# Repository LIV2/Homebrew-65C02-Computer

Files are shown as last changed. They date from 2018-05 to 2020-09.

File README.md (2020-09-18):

# Homebrew-65C02-Computer

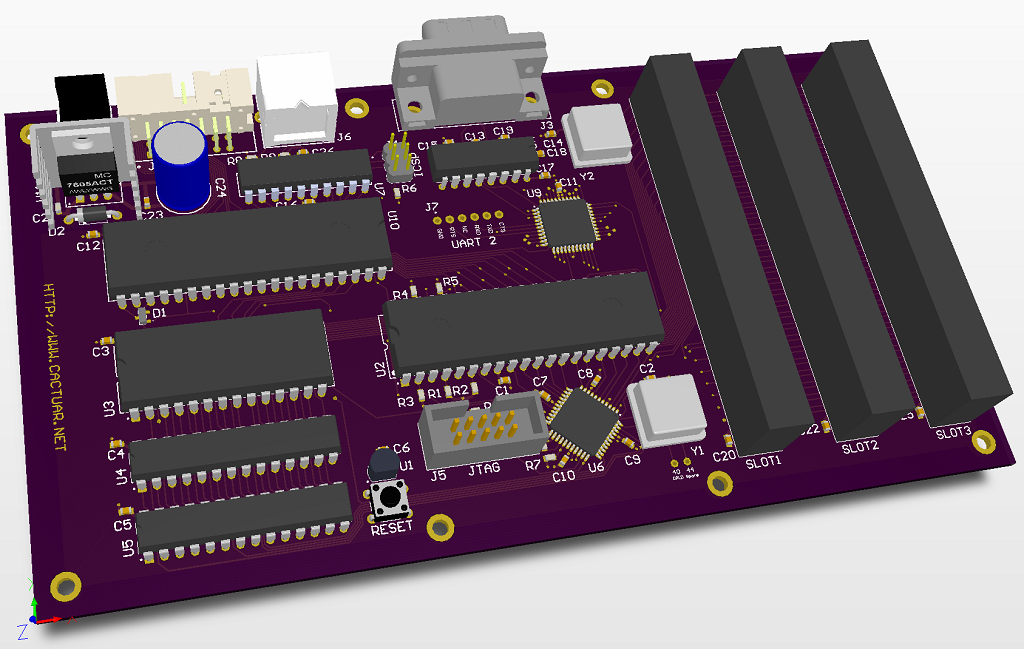
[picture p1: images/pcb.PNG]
PCB


# Introduction
This is a 65C02 based computer with on-board Serial, Parallel IO, PS/2 Keyboard support and 3 expansion slots.  
A VGA card will come later as an expansion card  

I am designing this in Circuitmaker, You can find the Circuitmaker project [here](https://circuitmaker.com/Projects/Details/Matt-Harlum/65C02-Computer-v12)  

# Memory Map
The Memory map I am using is currently as follows:  
0x0000-0xCFFF: RAM  
0xD000-0xD0FF: UART  
0xD100-0xD1FF: VIA  
0xD200-0xD2FF: IO Select 2  
0xD300-0xD3FF: IO Select 3  
0xD400-0xDFFF: Unused  
0xE000-0xFFFF: ROM  
This can be changed to suit your needs simply by changing the configuration of the CPLD.  

# Software
* [PS/2 Keyboard controller](https://github.com/LIV2/AVR-PS2-KBC)
* [ROM](https://github.com/LIV2/MHMON)

# Expansions
* [VGA card](https://github.com/LIV2/VGA-6502)
* [Floppy Disk card](https://github.com/LIV2/65C02-FDC)

----
Creative Commons Attribution 4.0 International License CC BY
Licensed under a [Creative Commons Attribution 4.0 International License (CC BY)](https://creativecommons.org/licenses/by/4.0/).

Except where otherwise noted, this content is published under a [CC BY license](https://creativecommons.org/licenses/by/4.0/), which means that you can copy, redistribute, remix, transform and build upon the content for any purpose even commercially as long as you give appropriate credit, provide a link to the license, and indicate if changes were made. License details: [https://creativecommons.org/licenses/by/4.0/](https://creativecommons.org/licenses/by/4.0/)

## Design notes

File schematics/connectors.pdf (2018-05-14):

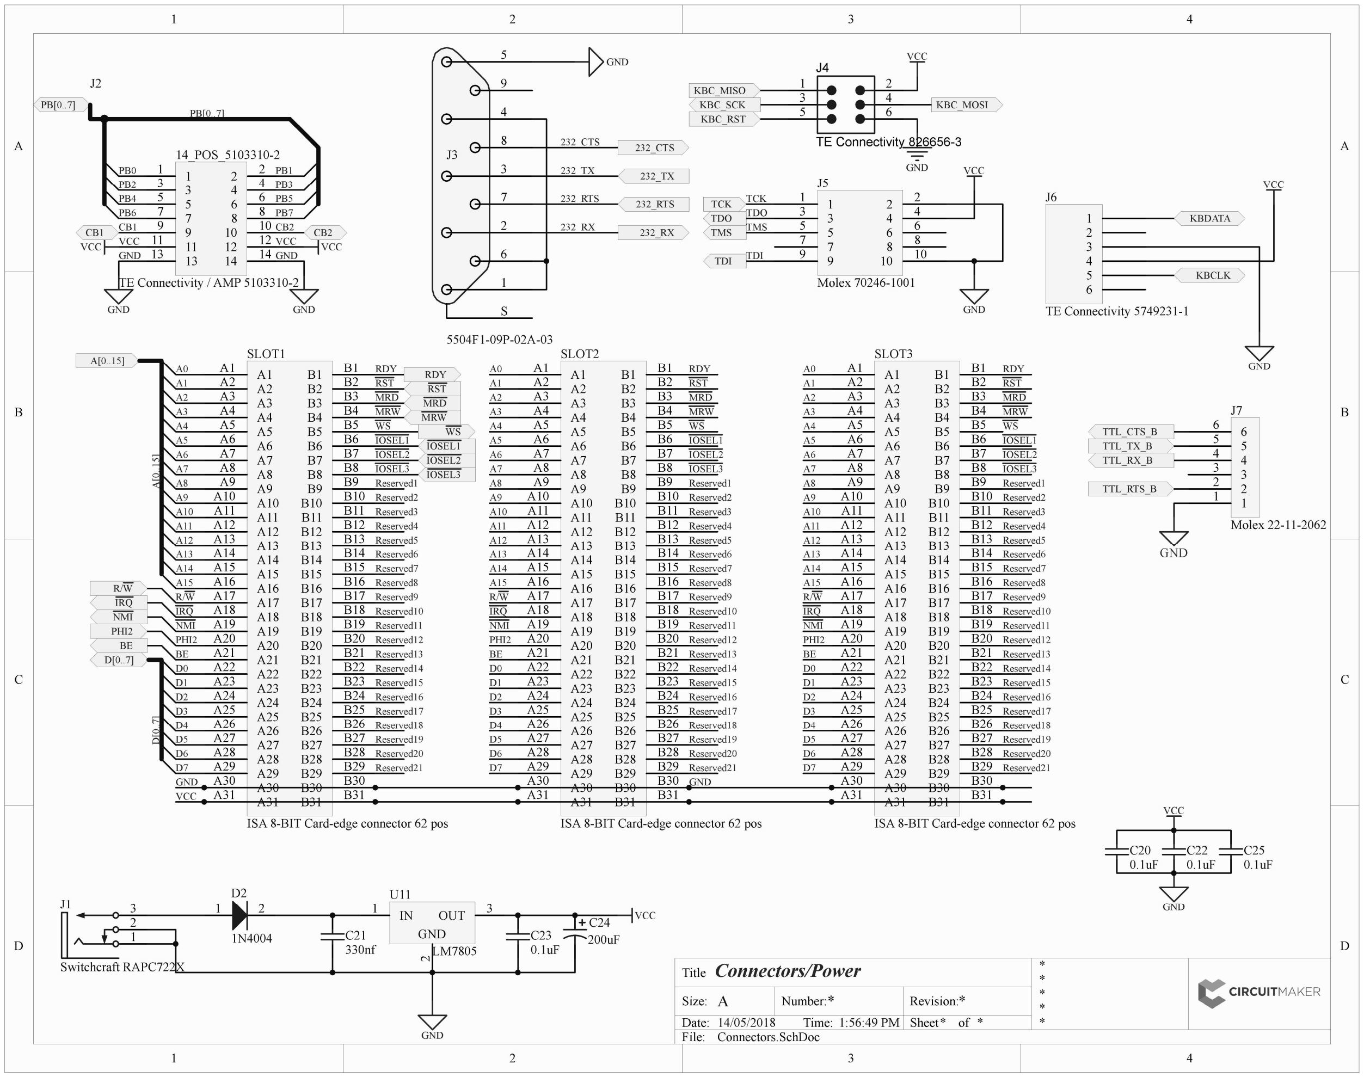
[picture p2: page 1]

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
* | *

## Connectors/Power

* | *
14/05/2018 | 1:56:49 PM
Connectors.SchDoc

Title

Size: | Number:
Date:
File:

Revision:
Time: | Sheet | of

A

PB[0..7]

PB0 | PB1
PB2 | PB3
PB4 | PB5
PB6 | PB7
CB1 | CB2
VCC | VCC
GND | GND
VCC | VCC
GND | GND

232_TX

232_CTS

232_RTS

232_RX

232_CTS

232_TX

232_RTS

232_RX

KBC_MISO

KBC_RST

KBC_SCK | KBC_MOSI

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
TE Connectivity 826656-3

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
10 10

J5

Molex 70246-1001

A1 A1
A2 A2
A3 A3
A4 A4
A5 A5
A6 A6
A7 A7
A8 A8
A9 A9
A10 A10
A11 A11
A12 A12
A13 A13
A14 A14
A15 A15
A16 A16
A17 A17
A18 A18
A19 A19
A20 A20
A21 A21
A22 A22
A23 A23
A24 A24
A25 A25
A26 A26
A27 A27
A28 A28
A29 A29
A30 A30
A31 A31
B1 | B1
B2 | B2
B3 | B3
B4 | B4
B5 | B5
B6 | B6
B7 | B7
B8 | B8
B9 | B9
B10 | B10
B11 | B11
B12 | B12
B13 | B13
B14 | B14
B15 | B15
B16 | B16
B17 | B17
B18 | B18
B19 | B19
B20 | B20
B21 | B21
B22 | B22
B23 | B23
B24 | B24
B25 | B25
B26 | B26
B27 | B27
B28 | B28
B29 | B29
B30 | B30
B31 | B31

SLOT1

ISA 8-BIT Card-edge connector 62 pos

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
PHI2
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
A[0..15]

D[0..7]

R/W
IRQ
NMI

# PHI2 D[0..7] A[0..15]

RDY
RST MRD MRD

MRW MRW
WS WS

3

1

2

J1

Switchcraft RAPC722X

C23
0.1uF

VCC

GND

C21
330nf

C20
0.1uF

A1 A1
A2 A2
A3 A3
A4 A4
A5 A5
A6 A6
A7 A7
A8 A8
A9 A9
A10 A10
A11 A11
A12 A12
A13 A13
A14 A14
A15 A15
A16 A16
A17 A17
A18 A18
A19 A19
A20 A20
A21 A21
A22 A22
A23 A23
A24 A24
A25 A25
A26 A26
A27 A27
A28 A28
A29 A29
A30 A30
A31 A31
B1 | B1
B2 | B2
B3 | B3
B4 | B4
B5 | B5
B6 | B6
B7 | B7
B8 | B8
B9 | B9
B10 | B10
B11 | B11
B12 | B12
B13 | B13
B14 | B14
B15 | B15
B16 | B16
B17 | B17
B18 | B18
B19 | B19
B20 | B20
B21 | B21
B22 | B22
B23 | B23
B24 | B24
B25 | B25
B26 | B26
B27 | B27
B28 | B28
B29 | B29
B30 | B30
B31 | B31

SLOT2

ISA 8-BIT Card-edge connector 62 pos

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
PHI2
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
0.1uF

A1 A1
A2 A2
A3 A3
A4 A4
A5 A5
A6 A6
A7 A7
A8 A8
A9 A9
A10 A10
A11 A11
A12 A12
A13 A13
A14 A14
A15 A15
A16 A16
A17 A17
A18 A18
A19 A19
A20 A20
A21 A21
A22 A22
A23 A23
A24 A24
A25 A25
A26 A26
A27 A27
A28 A28
A29 A29
A30 A30
A31 A31
B1 | B1
B2 | B2
B3 | B3
B4 | B4
B5 | B5
B6 | B6
B7 | B7
B8 | B8
B9 | B9
B10 | B10
B11 | B11
B12 | B12
B13 | B13
B14 | B14
B15 | B15
B16 | B16
B17 | B17
B18 | B18
B19 | B19
B20 | B20
B21 | B21
B22 | B22
B23 | B23
B24 | B24
B25 | B25
B26 | B26
B27 | B27
B28 | B28
B29 | B29
B30 | B30
B31 | B31

SLOT3

ISA 8-BIT Card-edge connector 62 pos

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
PHI2
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
0.1uF

PB[0..7]

BE

CB1 | CB2
WS | WS

KBDATA

KBCLK

VCC

GND

1 2

D2

1N4004

IOSEL1 | IOSEL1
| IOSEL2 IOSEL3

IOSEL2
IOSEL3
Reserved1
Reserved2
Reserved3
Reserved4
Reserved5
Reserved6
Reserved7
Reserved8
Reserved9
Reserved10
Reserved11
Reserved12
Reserved13
Reserved14
Reserved15
Reserved16
Reserved17
Reserved18
Reserved19
Reserved20
Reserved21

IOSEL1
IOSEL2
IOSEL3
Reserved1
Reserved2
Reserved3
Reserved4
Reserved5
Reserved6
Reserved7
Reserved8
Reserved9
Reserved10
Reserved11
Reserved12
Reserved13
Reserved14
Reserved15
Reserved16
Reserved17
Reserved18
Reserved19
Reserved20
Reserved21

IOSEL1
IOSEL2
IOSEL3
Reserved1
Reserved2
Reserved3
Reserved4
Reserved5
Reserved6
Reserved7
Reserved8
Reserved9
Reserved10
Reserved11
Reserved12
Reserved13
Reserved14
Reserved15
Reserved16
Reserved17
Reserved18
Reserved19
Reserved20
Reserved21

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
5504F1-09P-02A-03

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
10 10
11 11 | 12 | 12
13 13 | 14 | 14

14_POS_5103310-2

J2

TE Connectivity / AMP 5103310-2

C24
200uF
IN 1 | OUT | 3 2

GND

U11

LM7805

1
2
3
4
5
6

J6

TE Connectivity 5749231-1

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
Molex 22-11-2062

GND

TTL_RTS_B

TTL_RX_B

TTL_TX_B

TTL_CTS_B

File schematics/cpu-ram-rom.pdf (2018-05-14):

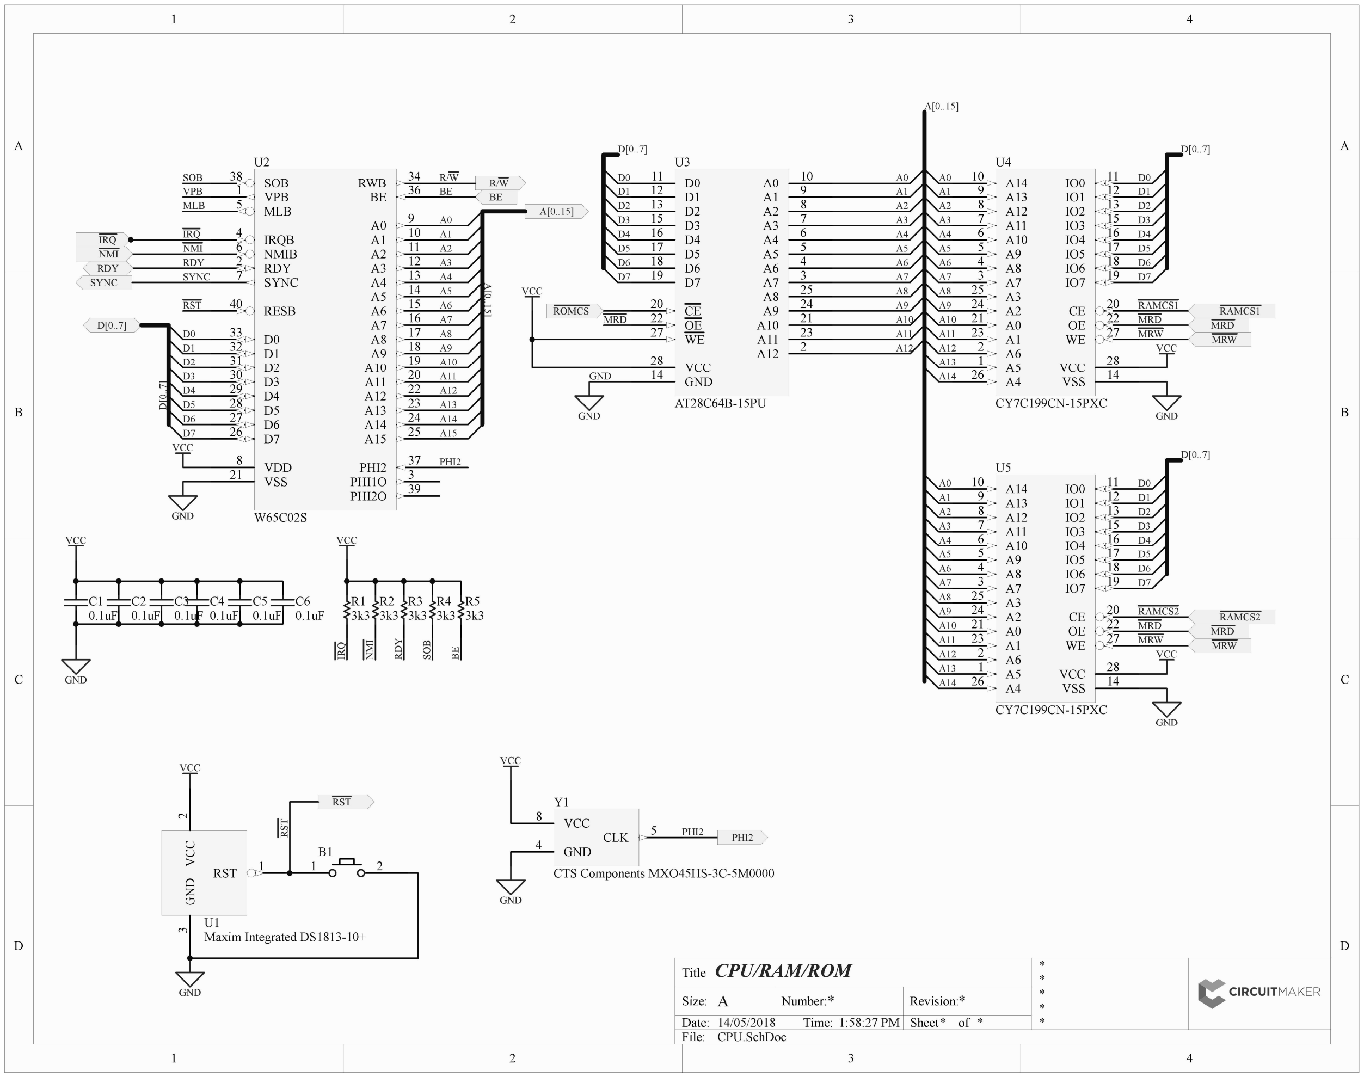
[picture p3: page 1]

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
* | *

## CPU/RAM/ROM

* | *
14/05/2018 | 1:58:27 PM
CPU.SchDoc

Title

Size: | Number:
Date:
File:

Revision:
Time: | Sheet | of

A

RAMCS1

MRW

MRD | MRD

GND VCC

## 2 GND

3

RST 1

U1
Maxim Integrated DS1813-10+

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
A[0..15]

D[0..7]

# RST RST

PHI2

SYNC

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
SYNC

PHI2 PHI2

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
A14 A[0..15] D[0..7]

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
A[0..15]

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
D[0..7]

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
D[0..7]

MRD
MRW

RAMCS1

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
3k3 IRQ | NMI | RDY | SOB | BE

VCC

GND

VCC

GND

VCC

GND

RAMCS2

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
D[0..7]

MRD
MRW

RAMCS2

VCC

GND

C1
0.1uF

C2
0.1uF

C3
0.1uF

C4
0.1uF

C5
0.1uF

C6
0.1uF

GND

VCC

VCC 8

GND 4

CLK 5

Y1

CTS Components MXO45HS-3C-5M0000

ROMCS

A12 | 2
A7 | 3
A6 | 4
A5 | 5
A4 | 6
A3 | 7
A2 | 8
A1 | 9
A0 | 10 D0 11
D1 12
D2 13

GND 14

D3 15
D4 16
D5 17
D6 18
D7 19

CE 20
A10 | 21 OE 22
A11 | | 23
A9 | 24 A8 | 25

WE 27

VCC 28

U3

AT28C64B-15PU

VPB 1

RDY 2

PHI1O 3

IRQB 4

MLB 5

NMIB 6

SYNC 7

VDD 8

A0 | 9
A1 | 10
A2 | 11
A3 | 12
A4 | 13
A5 | 14
A6 | 15
A7 | 16
A8 | 17
A9 | 18
A10 | 19
A11 | 20

VSS 21

A12 | 22
A13 | 23
A14 | 24
A15 | 25 D7 26 | D6 27 | D5 28 | D4 29 | D3 30 | D2 31 | D1 32 | D0 33
RWB | 34
BE | 36
PHI2 | 37

SOB 38

PHI2O 39

RESB 40

U2

W65C02S

A14 10
A13 9
A12 8
A11 7
A10 6
A9 5
A8 4
A7 3
A3 25
A2 24
A0 21
A1 23
A6 2
A5 1
A4 26
IO0 | 11
IO1 | 12
IO2 | 13
IO3 | 15
IO4 | 16
IO5 | 17
IO6 | 18
IO7 | 19
VSS | 14 VCC | 28
CE | | 20
OE | | 22
WE | | 27

U4

CY7C199CN-15PXC

A14 10
A13 9
A12 8
A11 7
A10 6
A9 5
A8 4
A7 3
A3 25
A2 24
A0 21
A1 23
A6 2
A5 1
A4 26
IO0 | 11
IO1 | 12
IO2 | 13
IO3 | 15
IO4 | 16
IO5 | 17
IO6 | 18
IO7 | 19
VSS | 14 VCC | 28
CE | | 20
OE | | 22
WE | | 27

U5

CY7C199CN-15PXC

1 2

B1

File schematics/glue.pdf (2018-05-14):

# A PHI2 PHI2

GND TMS | TCK WS | R/W

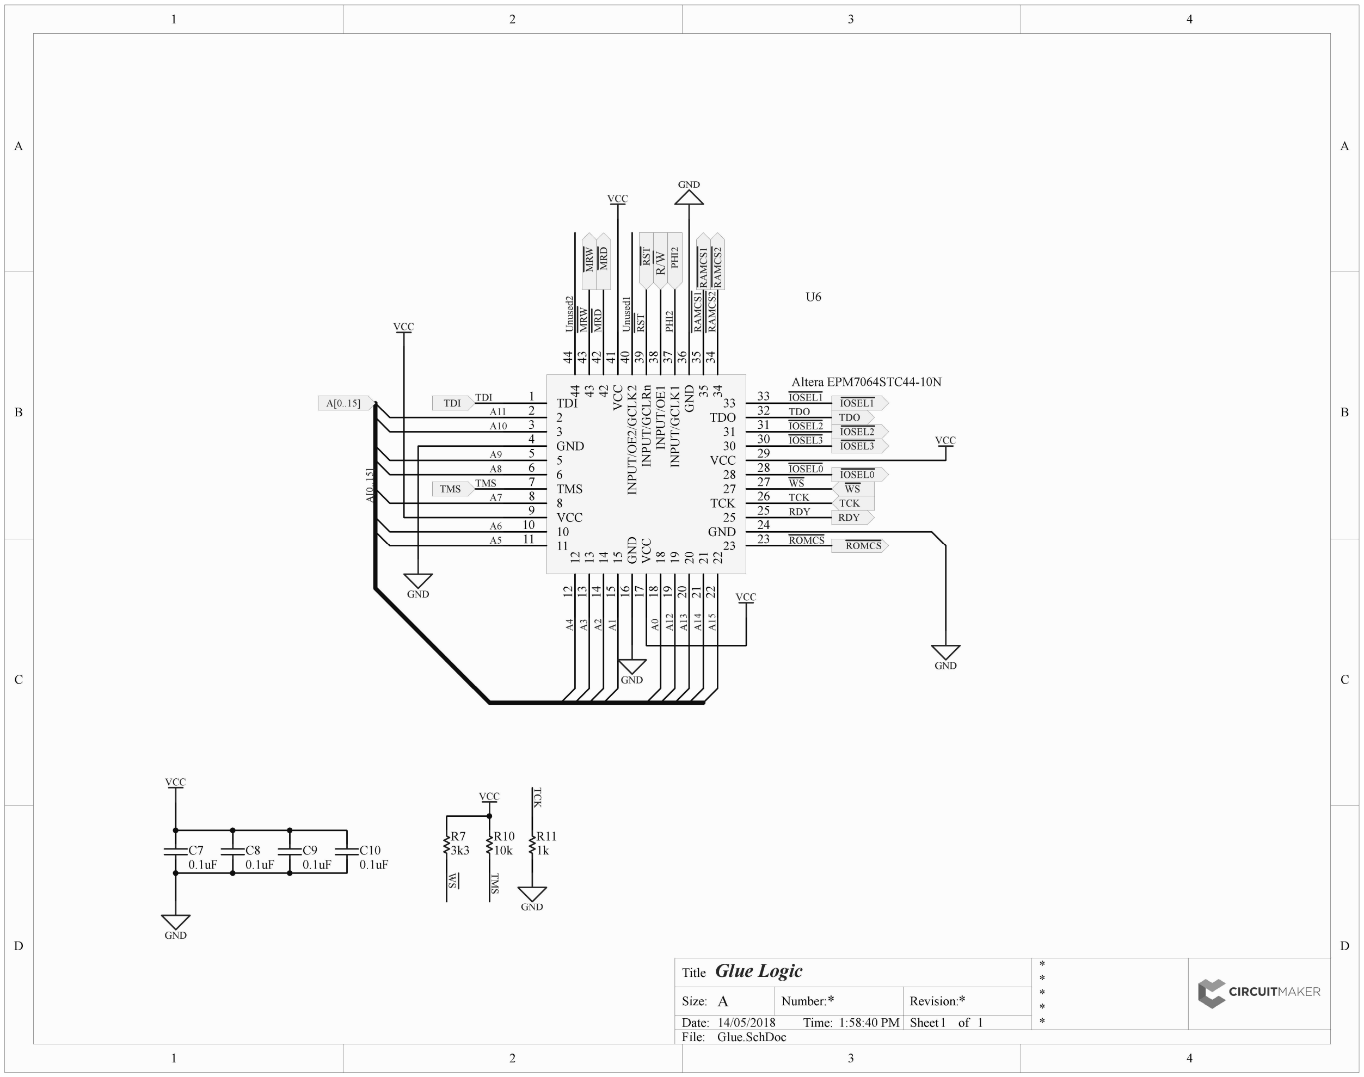
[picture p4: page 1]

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
## Glue Logic

* | *
14/05/2018 | 1:58:40 PM
Glue.SchDoc

Title

Size: | Number:
Date:
File:

Revision:
Time: | Sheet | of

WS

IOSEL0 IOSEL0

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
IOSEL1 | IOSEL1
IOSEL2 | IOSEL2
IOSEL3 | IOSEL3

RDY RDY

C7
0.1uF

C8
0.1uF

C9
0.1uF

C10
0.1uF

VCC

GND | RAMCS¹ RAMCS² RAMCS¹ RAMCS² MRW MRD MRW MRD

R7
3k3
VCC A⁴ A³ A² A¹ | A⁰

A5

A6

A7

A8

A9

A10

A11 | A¹² A¹³ A¹⁴ A¹⁵

ROMCS ROMCS RST RST

GND

GND

GND

GND

VCC

VCC

VCC A[0..15]

A[0..15] | Unused2 | Unused1

TDI 1
2

2
3

3
GND 4
5

5
6

6
TMS 7
8

8
VCC 9
10 10
11 11 | 12 12 13 13 14 14 15 15 GND 16 VCC 17 18 18 19 19 20 20 21 21 22 22
23 | 23 GND | 24 25 | 25 TCK | 26 27 | 27 28 | 28 VCC | 29 30 | 30 31 | 31 TDO | 32 33³⁴ | 33 ³⁴ ³⁵ ³⁵ GND ³⁶ INPUT/GCLK¹ ³⁷ INPUT/OE¹ ³⁸ INPUT/GCLRn 39 INPUT/OE²/GCLK² ⁴⁰ VCC ⁴¹ 42 42 43 43 44 44

U6

Altera EPM7064STC44-10N

R10
10k

R11
1k

VCC

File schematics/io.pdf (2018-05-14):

# IRQ D[0..7]

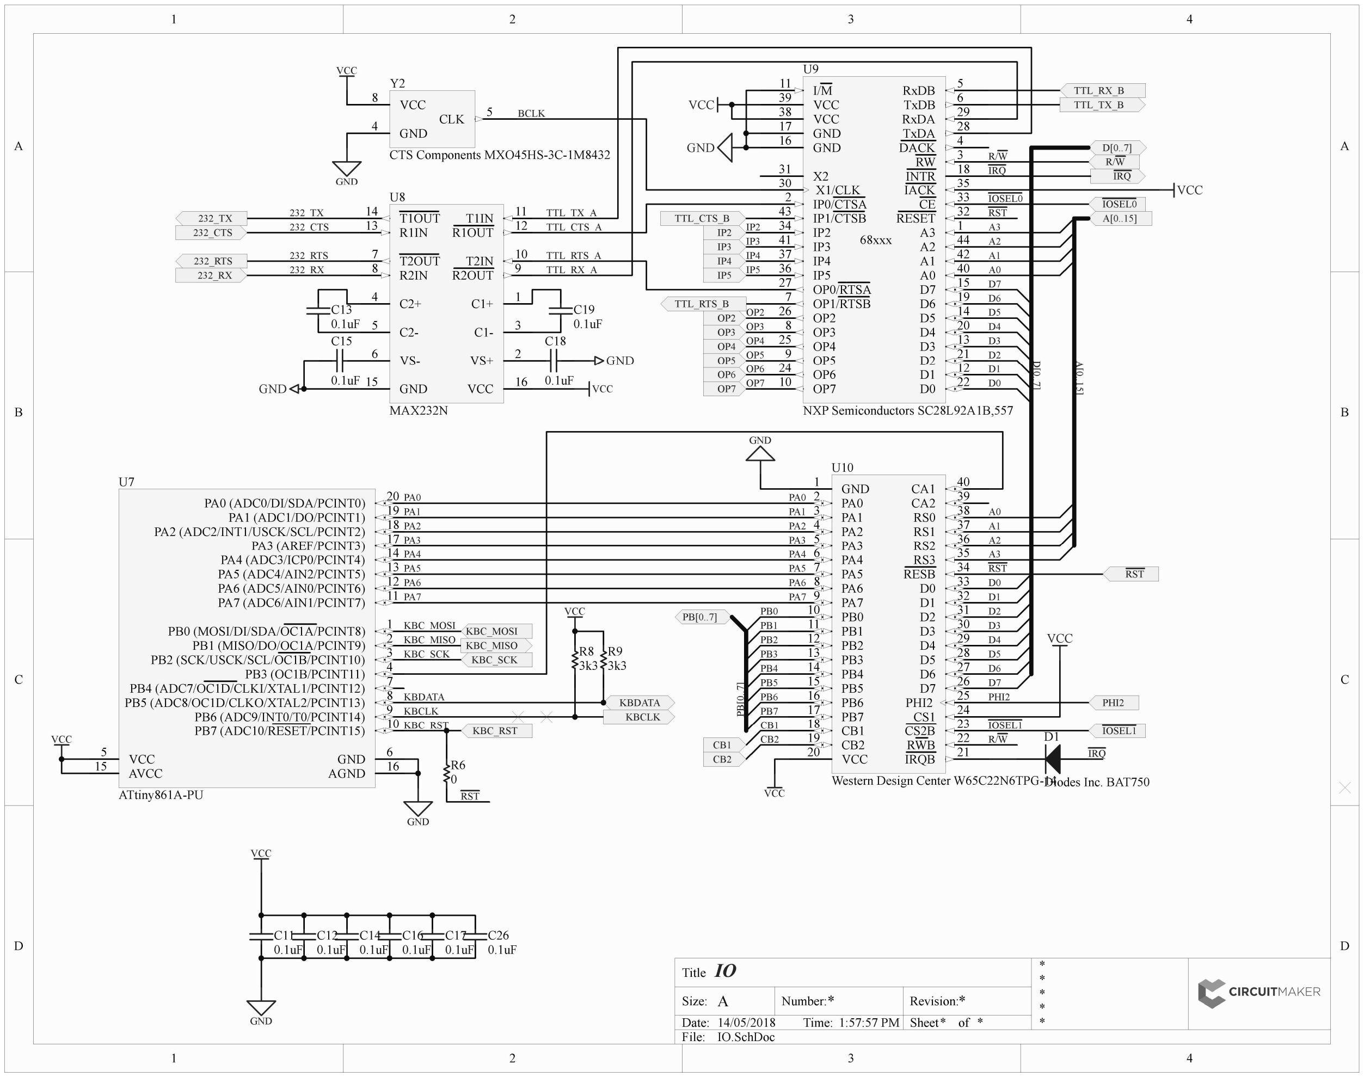
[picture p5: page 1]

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
* | *

IO

* | *
14/05/2018 | 1:57:57 PM
IO.SchDoc

Title

Size: | Number:
Date:
File:

Revision:
Time: | Sheet | of

A

TTL_RTS_A

TTL_TX_A
TTL_CTS_A

TTL_RX_A

232_RTS

232_TX
232_CTS

232_RX

C19
0.1uF

C13
0.1uF
C15

0.1uF

C18

0.1uF GND

GND

PHI2

R/W

D[0..7]

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
PHI2

R/W

VCC

GND

A[0..15]

A0
A1
A2
A3

# RST A[0..15]

IRQ

D1

Diodes Inc. BAT750

KBCLK

KBDATA

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
IOSEL1

IOSEL0

RST

KBDATA
KBCLK

PB[0..7] PB[0..7]

GND

KBC_MOSI
KBC_MISO
KBC_SCK

KBC_RST

KBC_MOSI
KBC_MISO
KBC_SCK

KBC_RST

232_CTS

232_TX

232_RTS
232_RX

GND

VCC

BCLK

C11
0.1uF

C12
0.1uF

C14
0.1uF

C16
0.1uF

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
0.1uF

CB1
CB2

VCC 8

GND 4

CLK 5

Y2

CTS Components MXO45HS-3C-1M8432

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
0.1uF
C1+ | 1
VS+ | 2
C1- | 3

C2+ 4

C2- 5

VS- 6

GND 15 | VCC | 16

T2OUT 7
R2IN 8 | R2OUT | 9
| T2IN | 10
T1IN | 11
R1OUT | 12 R1IN 13 | T1OUT 14

U8

MAX232N

PB7 (ADC10/RESET/PCINT15) | 10 PB6 (ADC9/INT0/T0/PCINT14) | 9
PB3 (OC1B/PCINT11) | | 4

VCC 5

PB4 (ADC7/OC1D/CLKI/XTAL1/PCINT12) | 7
PB5 (ADC8/OC1D/CLKO/XTAL2/PCINT13) | 8
PB2 (SCK/USCK/SCL/OC1B/PCINT10) | 3
PB1 (MISO/DO/OC1A/PCINT9) | 2
PB0 (MOSI/DI/SDA/OC1A/PCINT8) | 1
PA0 (ADC0/DI/SDA/PCINT0) | 20
PA1 (ADC1/DO/PCINT1) | 19
PA4 (ADC3/ICP0/PCINT4) | 14
AVCC 15 | AGND | 16
PA2 (ADC2/INT1/USCK/SCL/PCINT2) | 18
PA5 (ADC4/AIN2/PCINT5) | 13
PA6 (ADC5/AIN0/PCINT6) | 12
PA7 (ADC6/AIN1/PCINT7) | 11
GND | 6
PA3 (AREF/PCINT3) | 17

U7

ATtiny861A-PU

A3 1

IP0/CTSA 2

RW | 3
DACK | 4
RxDB | 5
TxDB | 6

OP1/RTSB 7

OP3 8

OP5 9

OP7 10

I/M 11

D1 | 12
D3 | 13
D5 | 14
D7 | 15
GND 16 | GND 17
INTR | 18
D6 | 19
D4 | 20
D2 | 21
D0 | 22 OP6 24

OP4 25

OP2 26

OP0/RTSA 27

TxDA | 28 RxDA | 29
X1/CLK 30 | X2 31
RESET | 32 CE | 33

IP2 34

IACK | | 35
IP5 36 | IP4 37
VCC 38 | VCC 39
A0 | 40

IP3 41
A1 42

IP1/CTSB 43

A2 68xxx | 44

U9

NXP Semiconductors SC28L92A1B,557

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
IOSEL0

IOSEL1

VCC

R/W
IRQ

GND

VCC

VCC

TTL_TX_B

TTL_RX_B

TTL_CTS_B

TTL_RTS_B

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
GND 1
PA0 2
PA1 3
PA2 4
PA3 5
PA4 6
PA5 7
PA6 8
PA7 9
PB0 10
PB1 11
PB2 12
PB3 13
PB4 14
PB5 15
PB6 16
PB7 17
CB1 18
CB2 19
VCC 20 | IRQB | 21 RWB | 22 CS2B | 23 CS1 | 24 PHI2 | 25 D7 | 26 D6 | 27 D5 | 28 D4 | 29 D3 | 30 D2 | 31 D1 | 32 D0 | 33 RESB | 34 RS3 | 35 RS2 | 36 RS1 | 37 RS0 | 38 CA2 | 39 CA1 | 40

U10

Western Design Center W65C22N6TPG-14

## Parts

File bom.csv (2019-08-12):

Designator | Comment | Description | Quantity
B1 | TE Connectivity / AMP 2-1825910-7 | Switch Tactile OFF (ON) SPST Extended Round Button PC Pins 0.05A 24VDC 100000Cycles 1.57N Thru-Hole Loose | 1
C1, C2, C3, C4, C5, C6, C7, C8, C9, C10, C11, C12, C13, C14, C15, C16, C17, C18, C19, C20, C22, C23, C25, C26 | 0.1uF | 0603 0.1uF Capacitor | 24
C21 | 330nf | CAP CER 0.33UF 16V 10% X5R 0603 | 1
C24 | 200uF | Cap Aluminum 1000uF 16V 20% (10 X 16mm) Radial Aluminum Cylindrical Can 5mm 680mA 2000 hr 85°C Bulk | 1
D1 | Diodes Inc. BAT750 | VR = 40V IF = 750mA VF < 490mV @ 750mA SOT23 | 1
D2 | 1N4004 | 1N400 Series 400 V 1 A Through Hole General Purpose Rectifier - DO-41 | 1
J1 | Switchcraft RAPC722X | Conn; AV; Power; Jack; Mini; 2.0mmPinDia; RtAngle; Thru-hole; forS760, S765Plug | 1
J2 | TE Connectivity / AMP 5103310-2 | Pin strip Contact spacing: 2.54 mm Total number of pins: 14 TE Connectivity 1 pc(s) | 1
J3 | 5504F1-09P-02A-03 | D SUB CONNECTOR, PADS +40%, STANDARD, 9POS, PLUG; Connector Type: D Sub; No. of Contacts: 9; D Sub Shell Size: DE; Connector Bod... | 1
J4 | TE Connectivity 826656-3 | TE Connectivity AMPMODU Series, 2.54mm Pitch 6 Way 2 Row Straight PCB Header, Solder Termination, 3A | 1
J5 | Molex 70246-1001 | Conn Shrouded Header HDR 10 POS 2.54mm Solder ST Thru-Hole C-Grid???? Tray | 1
J6 | TE Connectivity 5749231-1 | Conn Miniature Circular DIN RCP 6 POS Solder RA Thru-Hole 6 Terminal 1 Port Tube | 1
J7 | Molex 22-11-2062 | KK® 254 Solid Header, Vertical, with Friction Lock, 6 Circuits, Gold (Au) Plating | 1
R1, R2, R3, R4, R5, R7, R8, R9 | 3k3 | Thick Film Resistors - SMD 1/10watt 3.3Kohms 1% | 8
R6 | 0 | Thick Film Resistors - SMD 1/10watt 3.3Kohms 1% | 1
R10 | 10k | Res Thick Film 0603 10K Ohm 1% 0.1W(1/10W) ±100ppm/C Molded SMD Automotive Paper T/R | 1
R11 | 1k | RESISTOR, ANTI SULFUR, 1K, 0603, 5%; Resistance: 1kohm; Resistance Tolerance: ± 5%; Power Rating: 100mW; Voltage Rati... | 1
SLOT1, SLOT2, SLOT3 | ISA 8-BIT Card-edge connector 62 pos | 62 pos card-edge connector | 3
U1 | Maxim Integrated DS1813-10+ | Processor Supervisor 4.35V 0V to 5.5V 3-Pin TO-92 | 1
U2 | W65C02S | 6502 CPU | 1
U3 | AT28C64B-15PU | AT28C64B Series 64 KB (8 K x 8) 5.5 V High-Performance Parallel EEPROM - DIP-28 | 1
U4, U5 | CY7C199CN-15PXC | SRAM Chip Async Single 5V 256K-bit 32K x 8 15ns 28-Pin PDIP Tube | 2
U6 | Altera EPM7064STC44-10N | IC: CPLD; SMD; TQFP44; Series: Max 7000; Amount of macr | 1
U7 | ATtiny861A-PU | 8-bit AVR Microcontroller, 2.7-5.5V, 20MHz, 8KB Flash, 512 Bytes EEPROM, 512 Bytes SRAM, 20-pin PDIP, Industrial Grade (-40°C to 85°C) | 1
U8 | MAX232N | Dual EIA-232 Driver / Receiver, 0 to 70 degC, 16-Pin PDIP (N), Pb-Free (RoHS) | 1
U9 | NXP Semiconductors SC28L92A1B,557 | Integrated circuits from leading manufacturers. Please read our extensive documentation which is free to download. | 1
U10 | Western Design Center W65C22N6TPG-14 | W65C22N Versatile Interface Adapter (VIA) | 1
U11 | LM7805 | Linear Voltage Regulator, Positive, 5.0 V, 1.0 A Vout: 5.0 V; TJ = 0°C to +125°C | 1
Y1 | CTS Components MXO45HS-3C-5M0000 | Oscillator XO 5MHz ??50ppm 50pF (Stability) HCMOS/TTL 55% 5V 4-Pin Metal DIP Thru-Hole Tray | 1
Y2 | CTS Components MXO45HS-3C-1M8432 | Oscillator XO 1.8432MHz ±50ppm 50pF (Stability) HCMOS/TTL 55% 5V 4-Pin Metal DIP Thru-Hole Tray | 1

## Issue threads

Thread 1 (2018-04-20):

RW not connected to CPLD, /MRD & /MWR connected to output pins

LIV2, 2018-04-20:
RW is not connected to the CPLD
/MRD and /MWR are connected to input pins of the CPLD

Need to swap with some of the unused pins, possibly unroute a0-7 as they aren't currently needed

Closed 2018-04-21.

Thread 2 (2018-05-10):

Reset button + VIA pinout are wrong

LIV2, 2018-05-10:
VCC/GND are transposed on the 65C22
Reset button pinout is wrong which causes RST to be permanently held low

Closed 2018-05-14.

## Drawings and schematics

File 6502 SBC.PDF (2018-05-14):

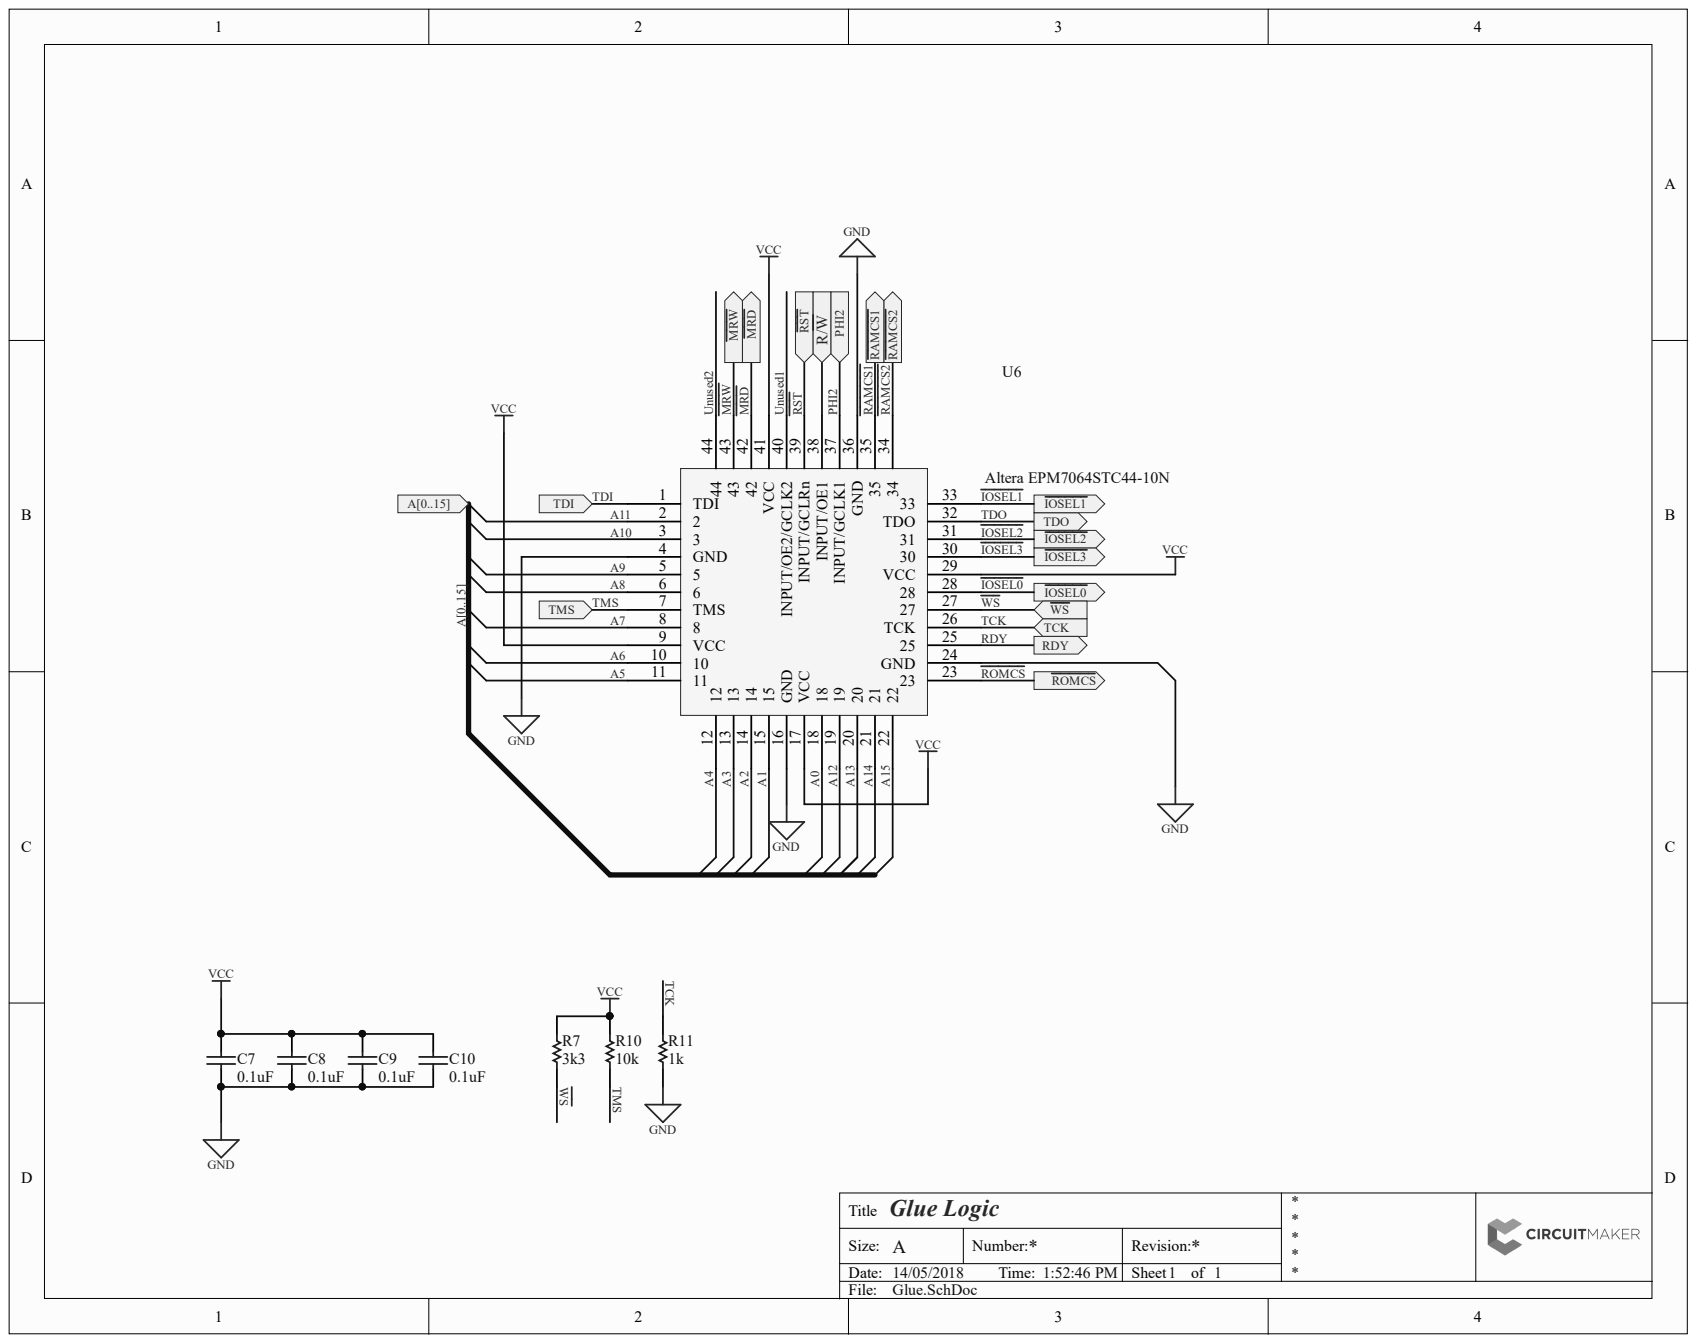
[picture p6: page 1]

D 36 INPUT/GCLK1 37 INPUT/OE1 38 INPUT/GCLRn 39 INPUT/OE2/GCLK2 40 VCC 41 42 42 43 43 44 44

22 22 23 23 GND 24 25 25 TCK 26 27 27 28 28 VCC 29 30 30 31 31 TDO 32 33

A9 A8 TMS TMS A7 | 5 5 6 6 TMS 7 8 8 VCC 9

Glue Logic Title | * *

Size: A | Number: * | Revision: *

Date: 14/05/2018 Time: 1:52:46 PM | | Sheet of 1

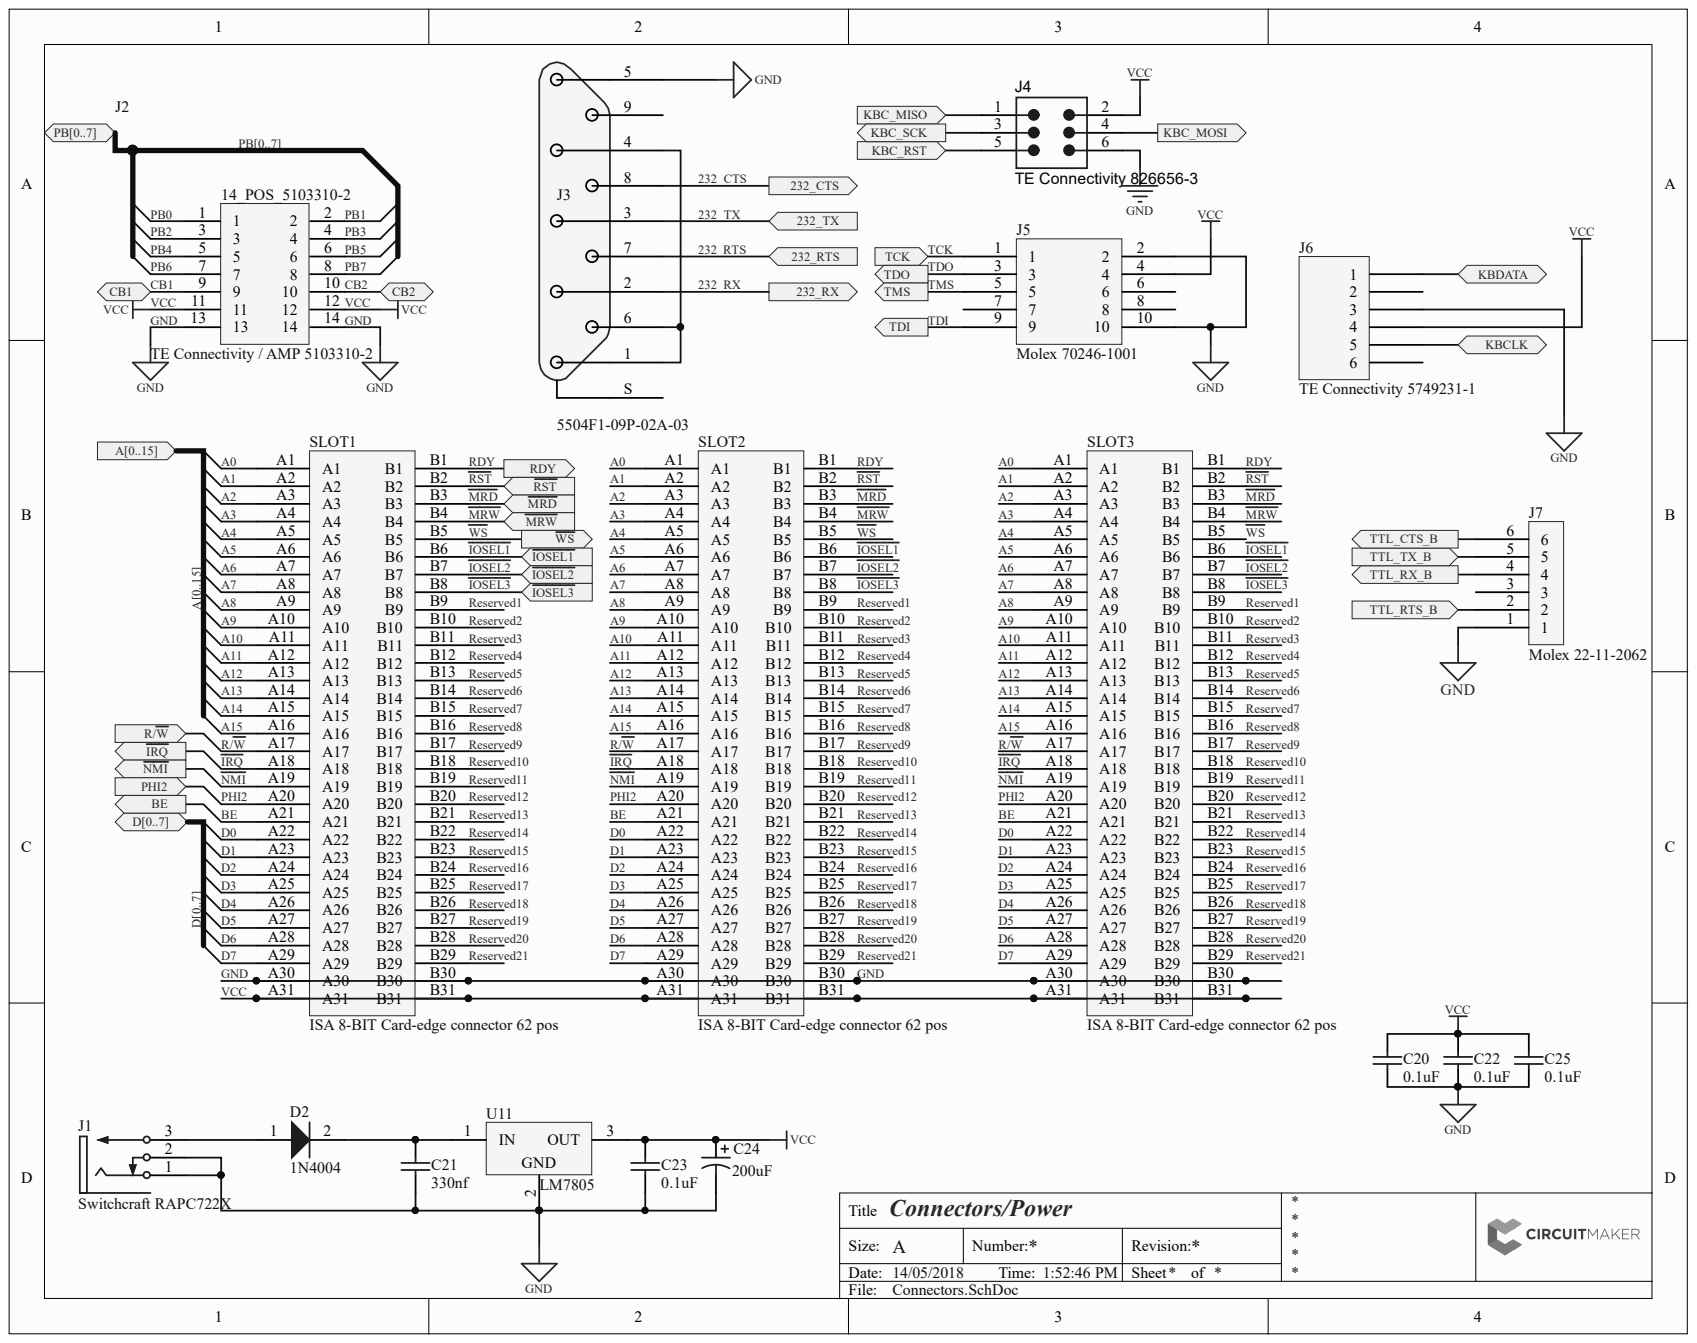
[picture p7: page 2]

ISA 8-BIT Card-edge connector 62 pos

Connectors/Power Title | * *

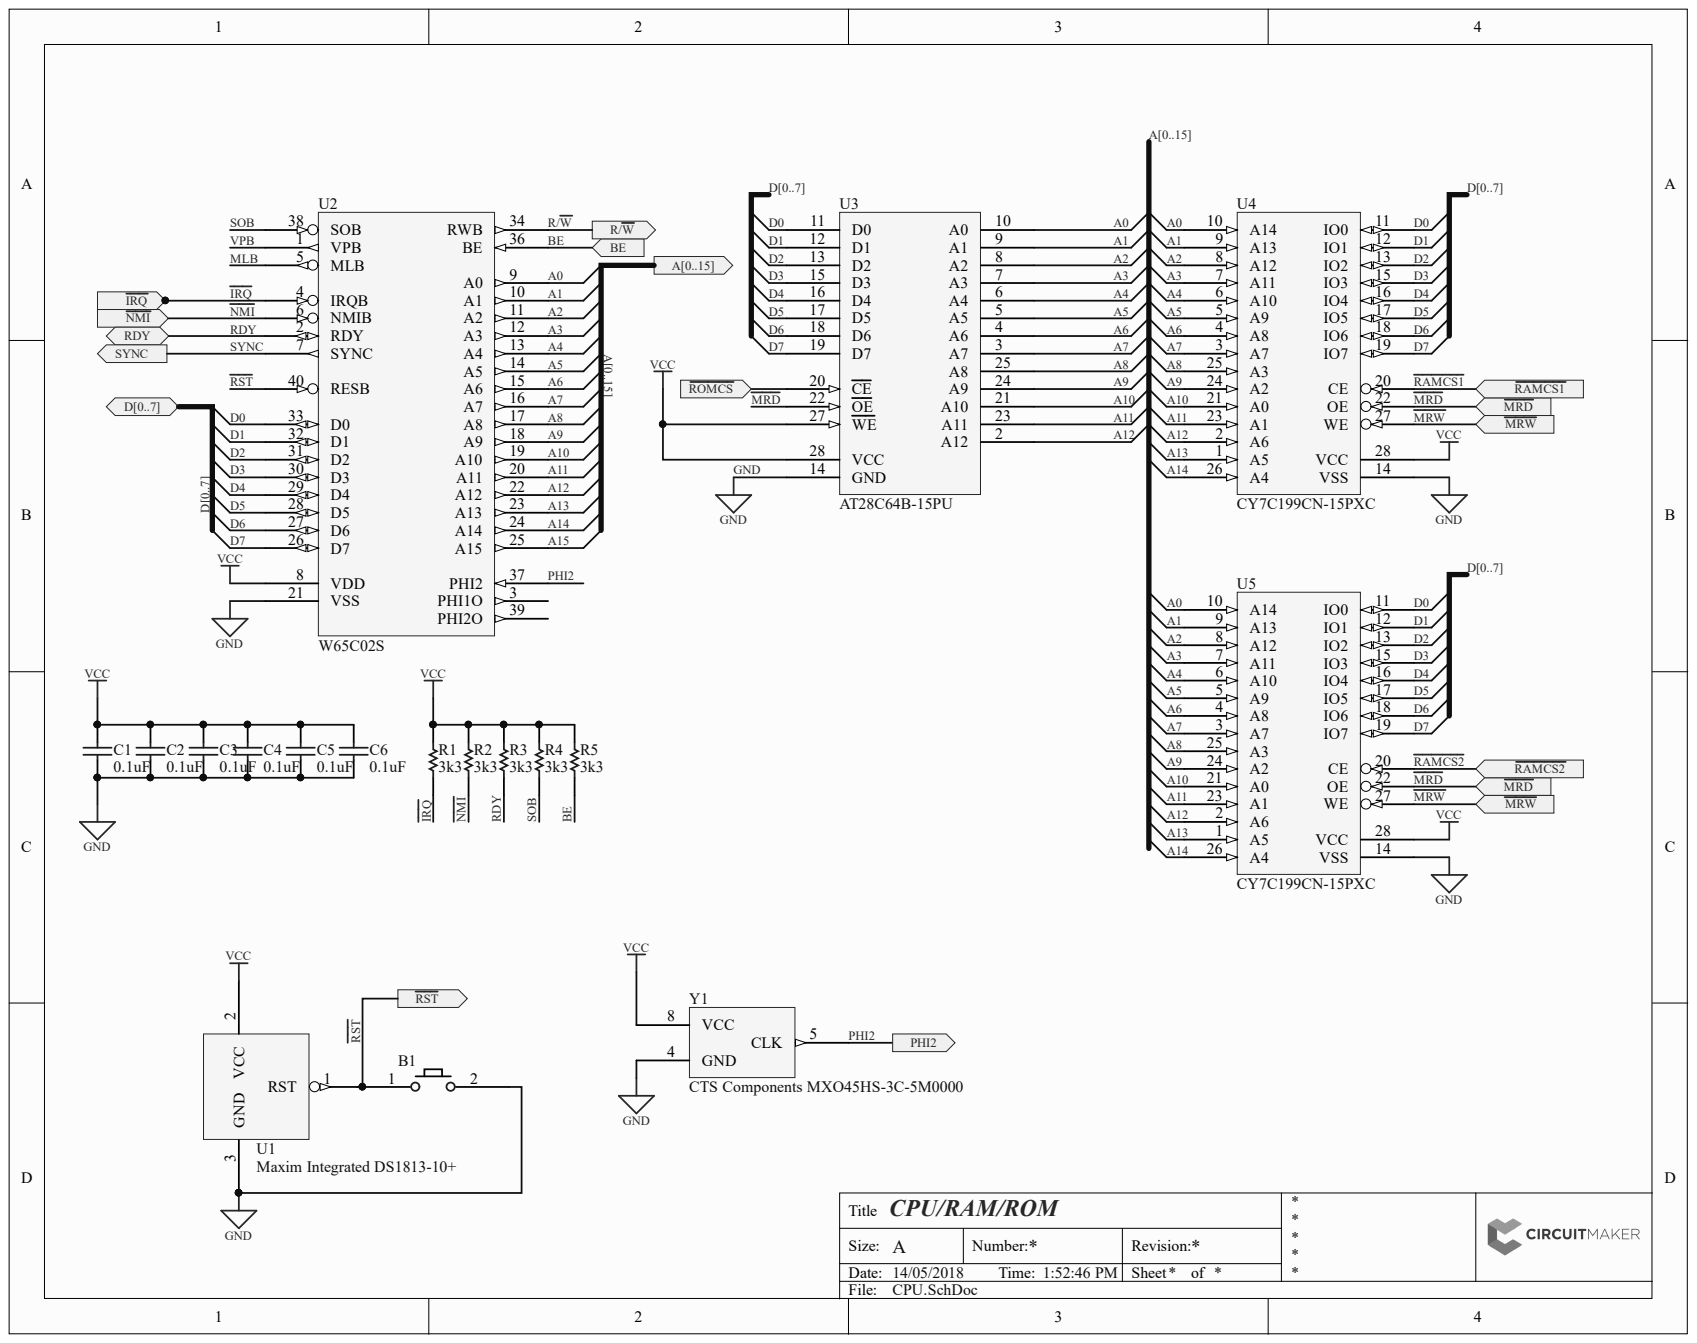
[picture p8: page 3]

Maxim Integrated DS1813-10+

CPU/RAM/ROM Title | * *

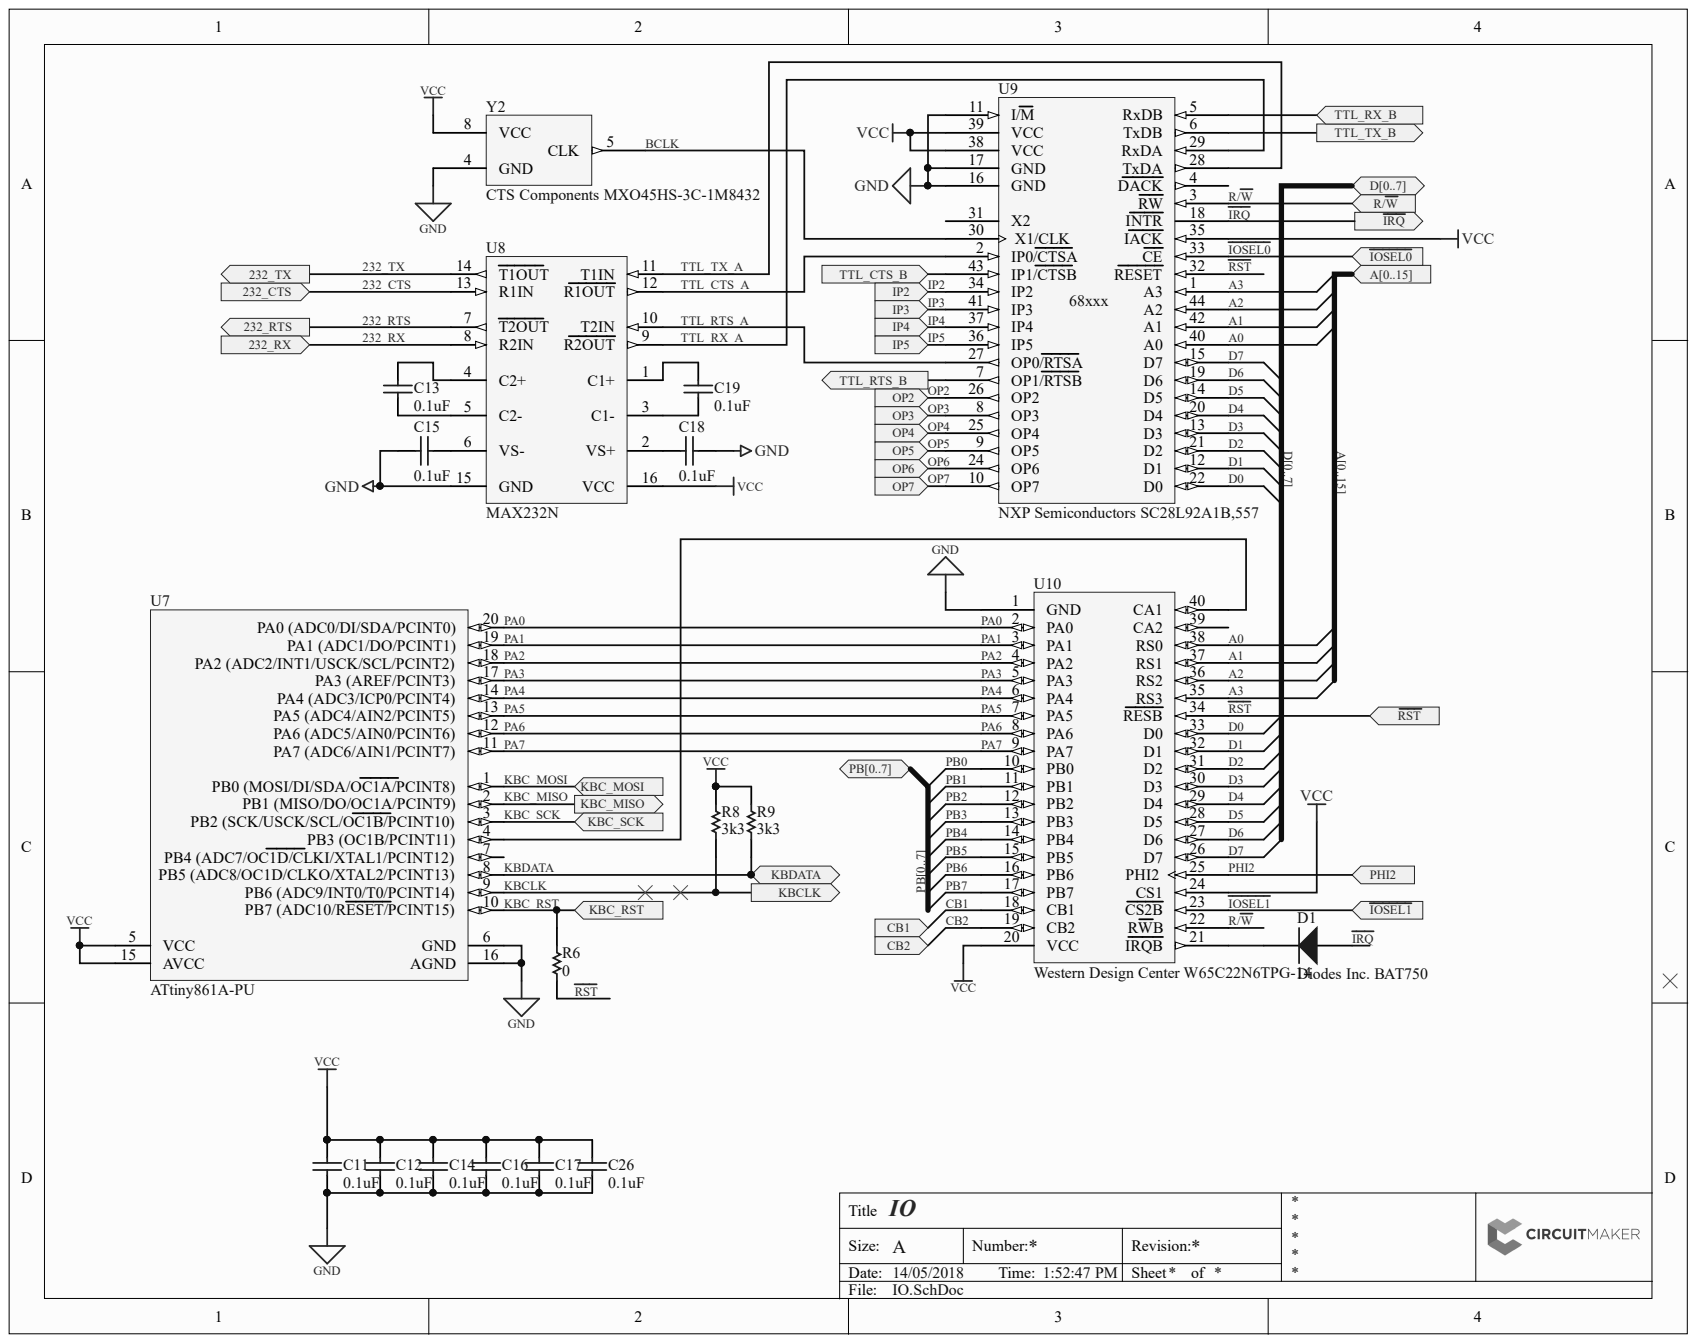
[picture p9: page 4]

TTL_CTS_A | IP2 | | IP2 34 | A3
TTL_RTS_A | IP3 | IP3 41 | A2

TTL_RX_A | IP5 | | | A0

OP0/RTSA 27 | D7

C19 | OP1/RTSB 7 | D6

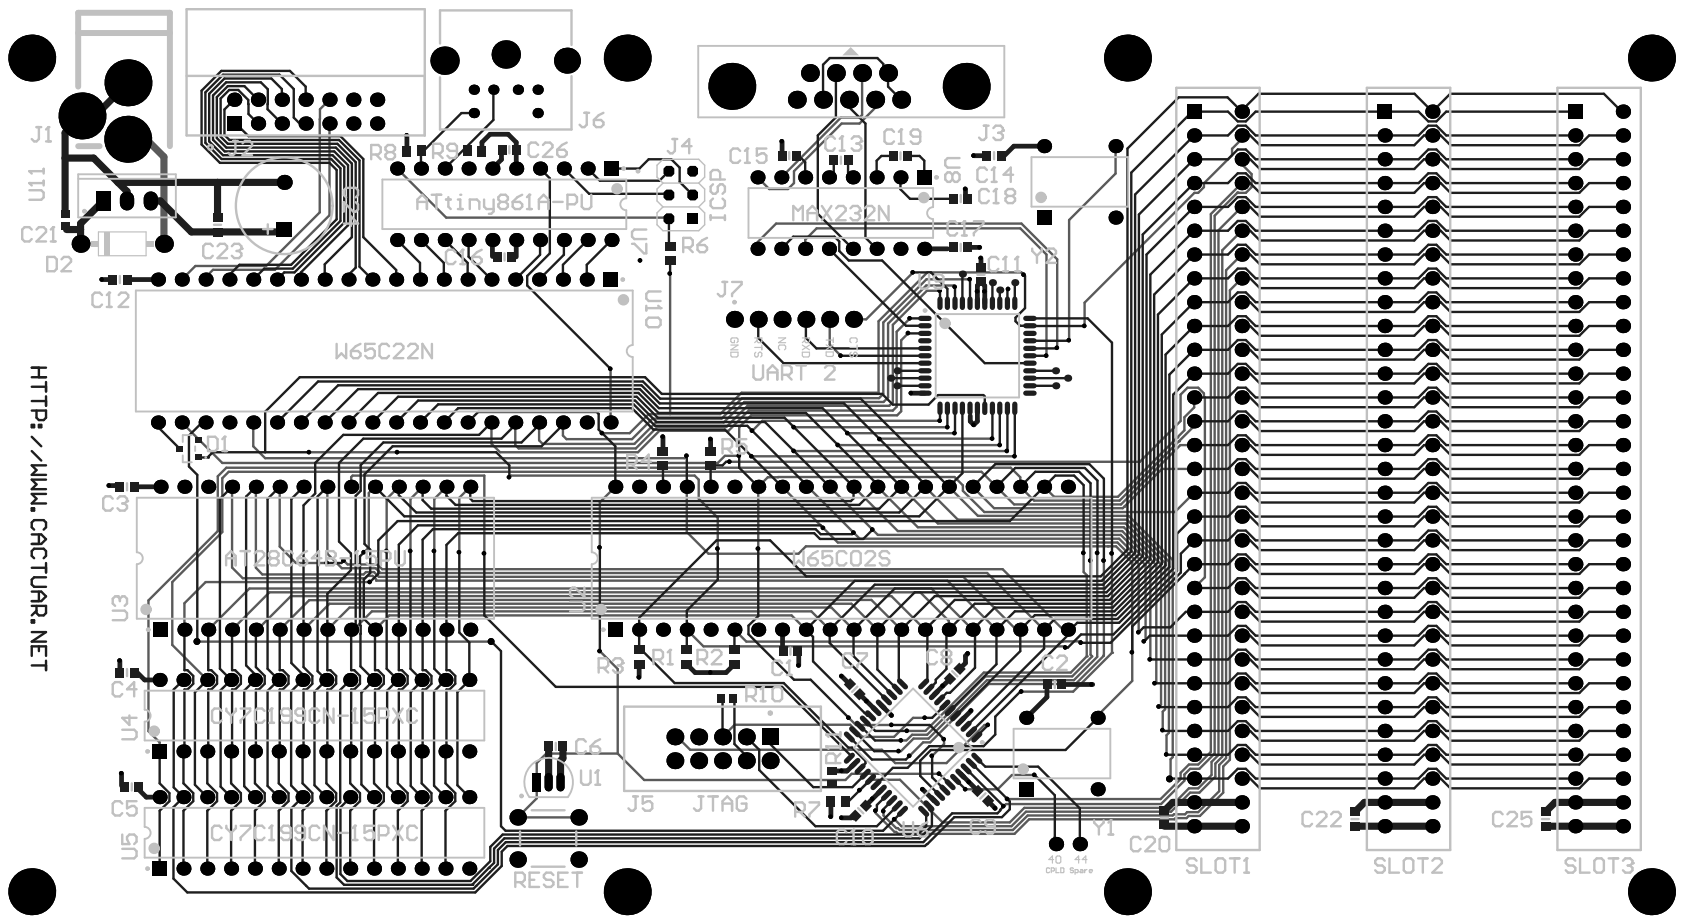
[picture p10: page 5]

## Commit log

2018-04-21 Issue #1: Fixes MRD/MWR on CPLD Inputs, Fixes missing R/W to CPLD
    [PCB1.GBL, PCB1.GBO, PCB1.GBP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]
2018-05-14 * Replaces 65C51 with SC28L92 due to the TX bit bug with the W65C51 * Fixes issue #2: Incorrect 65C22 & Reset button pinouts
    [PCB1.GBL, PCB1.GBO, PCB1.GBS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]
2018-08-04 Fix ICSP Pin hole sizes & Connect mounting holes to GND
    [PCB1.GBL, PCB1.GBP, PCB1.GBS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]
2019-08-12 Update readme, add VHDL for glue logic
2019-08-12 Add Bill of materials
    [bom.csv]
2020-07-11 Update glue logic
    IOSEL0 must be qualified by PHI2 to prevent false read/writes to UART
    registers
2020-09-23 Add CircuitMaker files
    [CPU.SchDoc, Connectors.SchDoc, Glue.SchDoc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]
